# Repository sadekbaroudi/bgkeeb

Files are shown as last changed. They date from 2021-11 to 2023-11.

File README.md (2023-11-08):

# Pronunciation

Baby Groot Keyboard (bgkeeb)

This is a reversible 100mm x 100mm pcb with support for mx or choc switches (no hotswap), per key led, rotary encoders, and exposes the SDA/SCL/GND/VCC lines in the form of the pimoroni trackball pins (meaning you can add that as well, though the case doesn't support it, so you'll need to devise your own mechanism).

Given the pcb is so small, pcb prototype manufacturers will fab this for very cheap, or even free. As of this writing, nextpcb will ship fab and ship this keyboard 100% for free (in green only). jlcpcb will fab and ship these for $2 (USD).

# PCBs

There are two pcbs, the choc version and the mx version.

For the mx version, see the pcb/mx directory in the repository
For the choc version, see the pcb/mx directory in the repository

# Support me!

I have spent a lot of time and money designing prototypes, testing, developing, etc. Any contributions would be greatly appreciated!

If you don't want to, or can't afford to support me, please send me a message to let me know you've built one, along with pictures. Also, feel free to submit a pull request with pictures into this repository. I'd be happy to showcase your build.

Reddit: /u/sadekbaroudi
Discord: sadekbaroudi#1258



# Firmware

You can use the firmware found here:
https://github.com/sadekbaroudi/qmk_firmware/tree/master/keyboards/fingerpunch/bgkeeb/

zmk firmware here: https://github.com/ezxzeng/zmk-bgkeeb

# Pictures

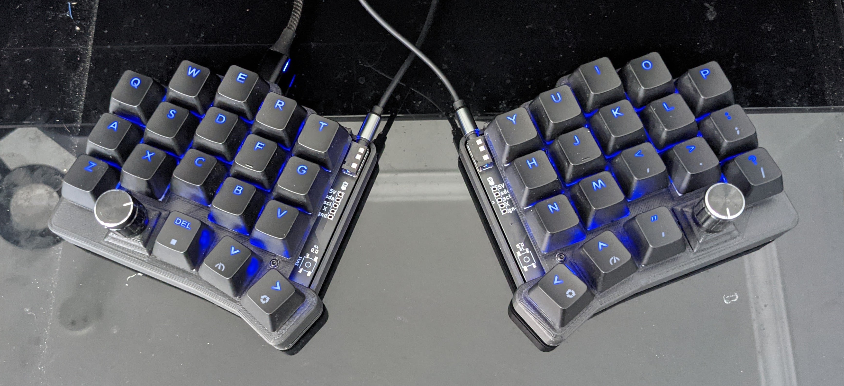
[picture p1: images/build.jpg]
build


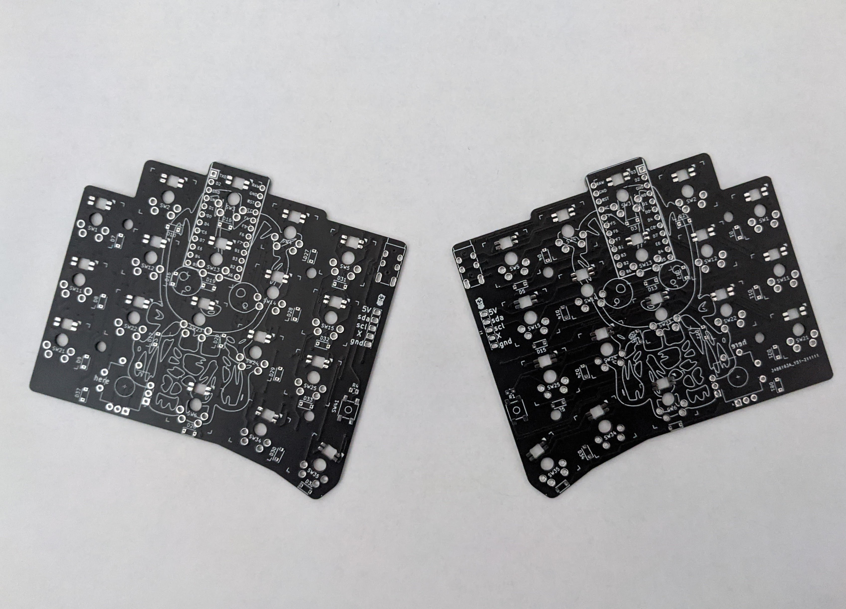
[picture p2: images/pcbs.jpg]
pcbs


# Submitted build pics

@ardakilic

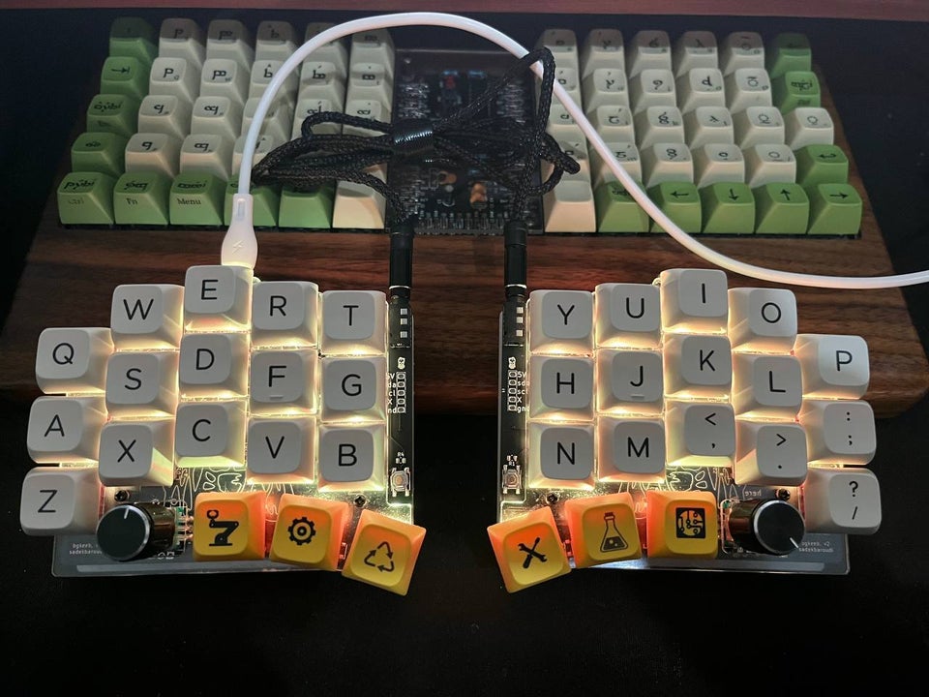
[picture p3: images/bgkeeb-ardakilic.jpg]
ardakilic-build


@carboncopy101

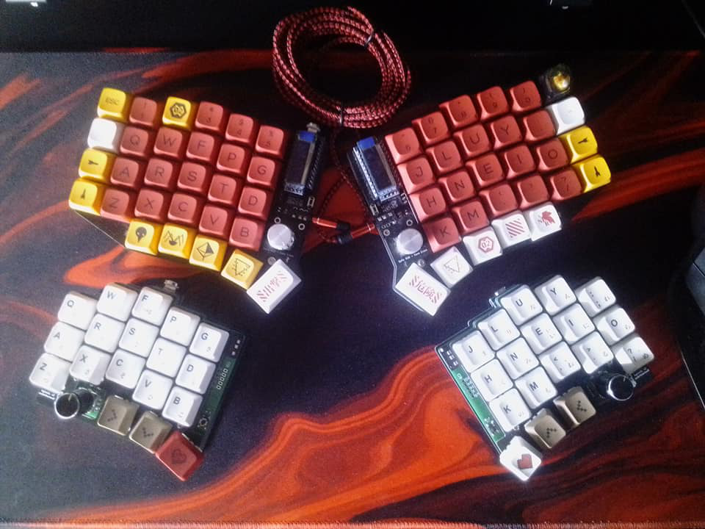
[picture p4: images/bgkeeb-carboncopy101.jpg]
cc101-build


@robopuff

cc101-build

@JulioPDX

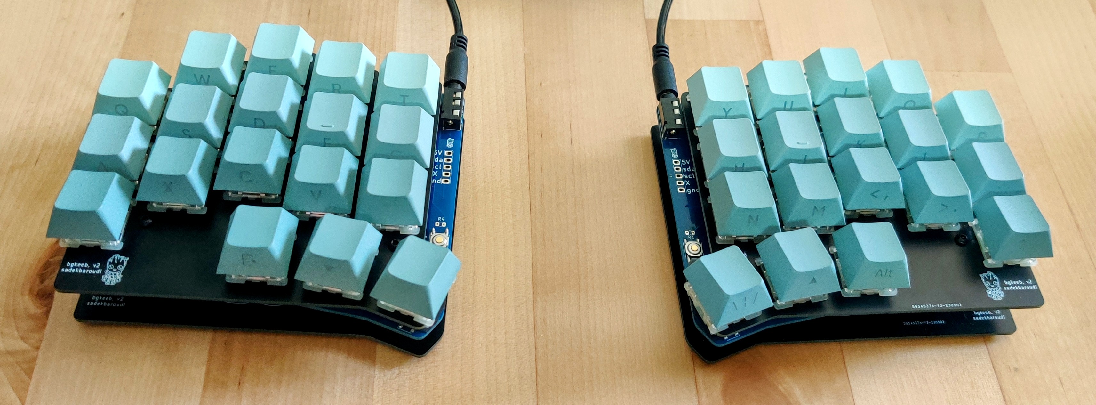
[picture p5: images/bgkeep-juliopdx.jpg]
juliopdx-build


@ezxzeng

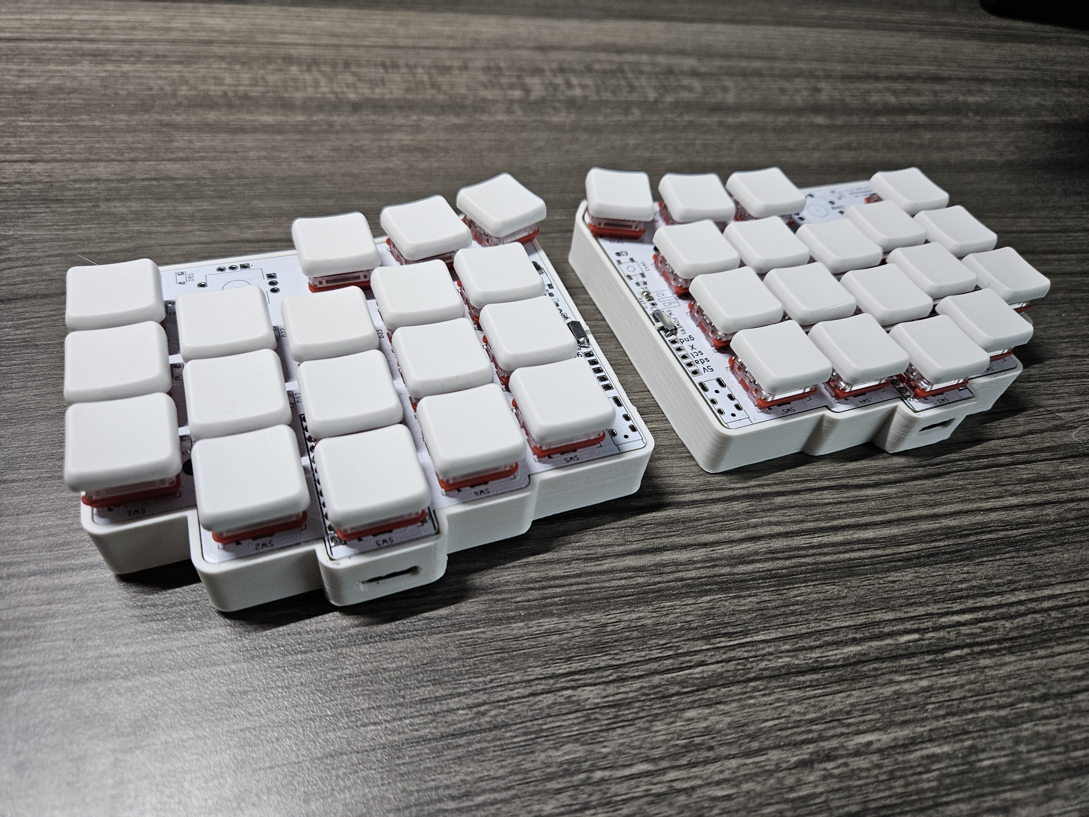
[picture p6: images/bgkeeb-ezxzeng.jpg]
ezxzeng-build

case for the wireless choc build found [here](https://cad.onshape.com/documents/f9433f7cbaacd819773968dc/w/7cd753696df5795c5e7db3c3/e/7a6c60eb671b22fb31dd6c76)

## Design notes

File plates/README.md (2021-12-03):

# FR-4 plates

Go into each directory, and fab the gerber.zip. 

You need the bottom plate and one of the two switchplates. If you are not going to use an encoder, use the no-encoder one

# Pictures

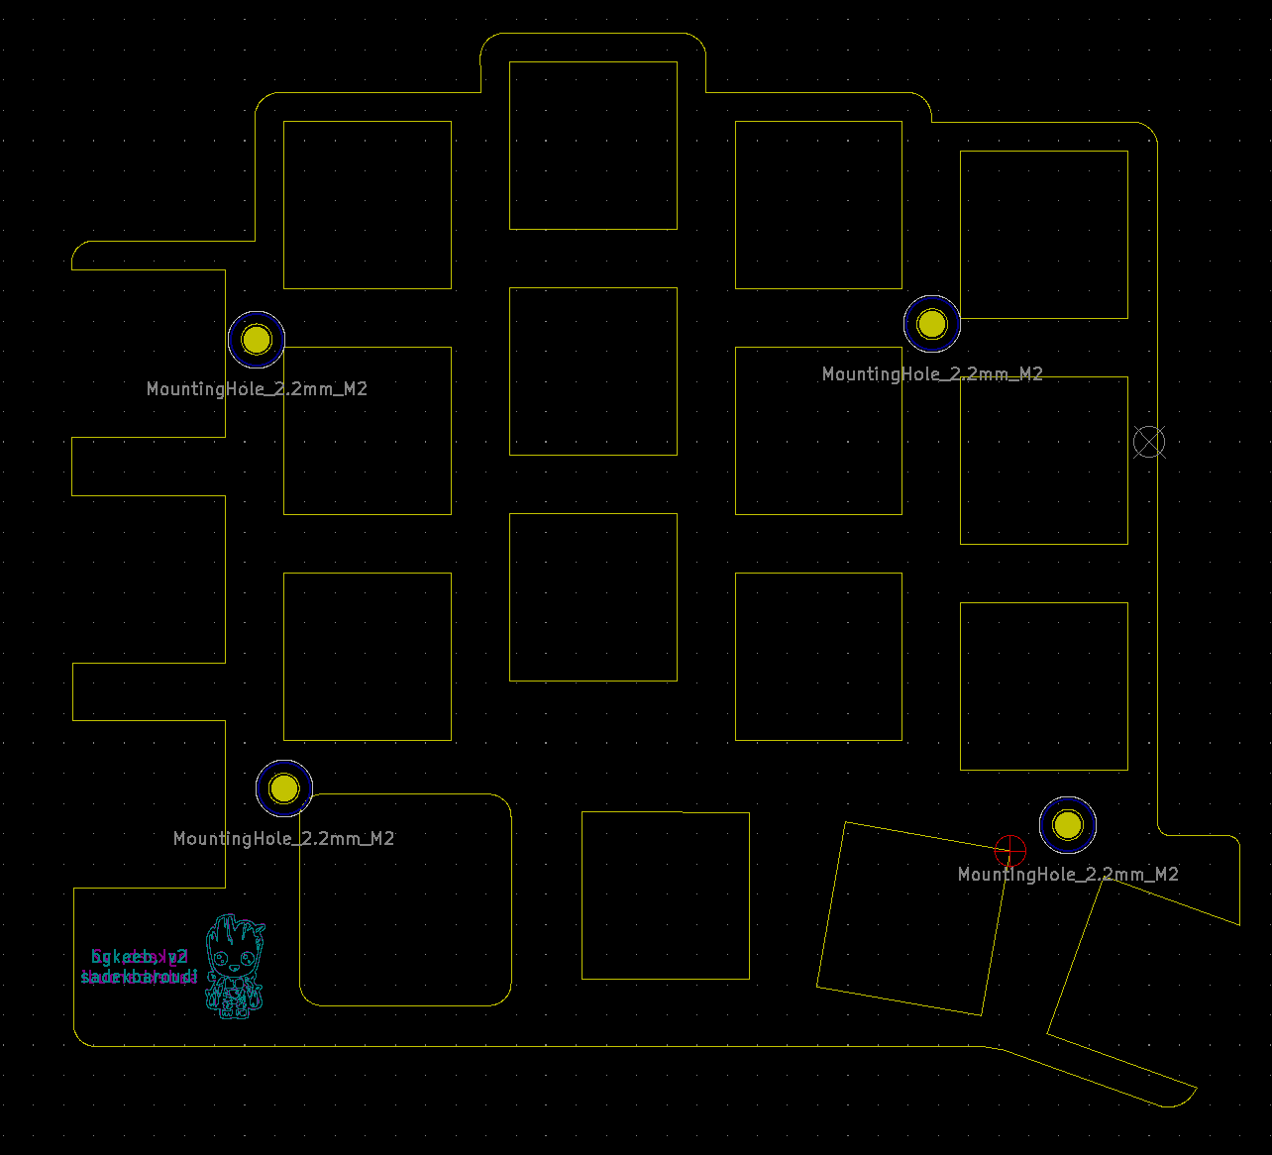
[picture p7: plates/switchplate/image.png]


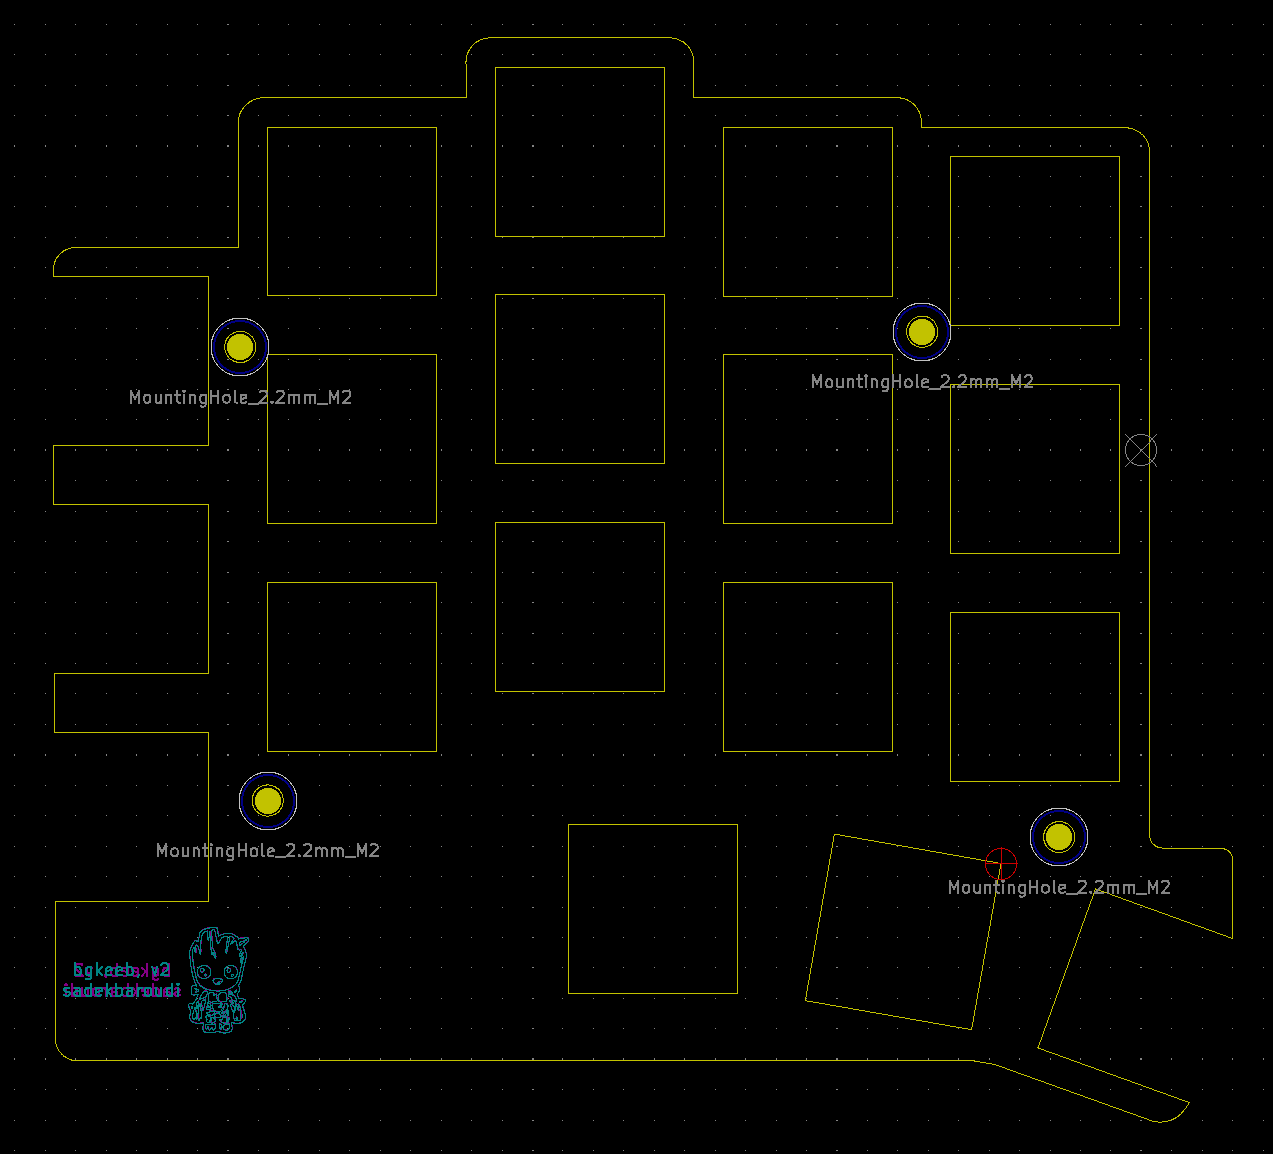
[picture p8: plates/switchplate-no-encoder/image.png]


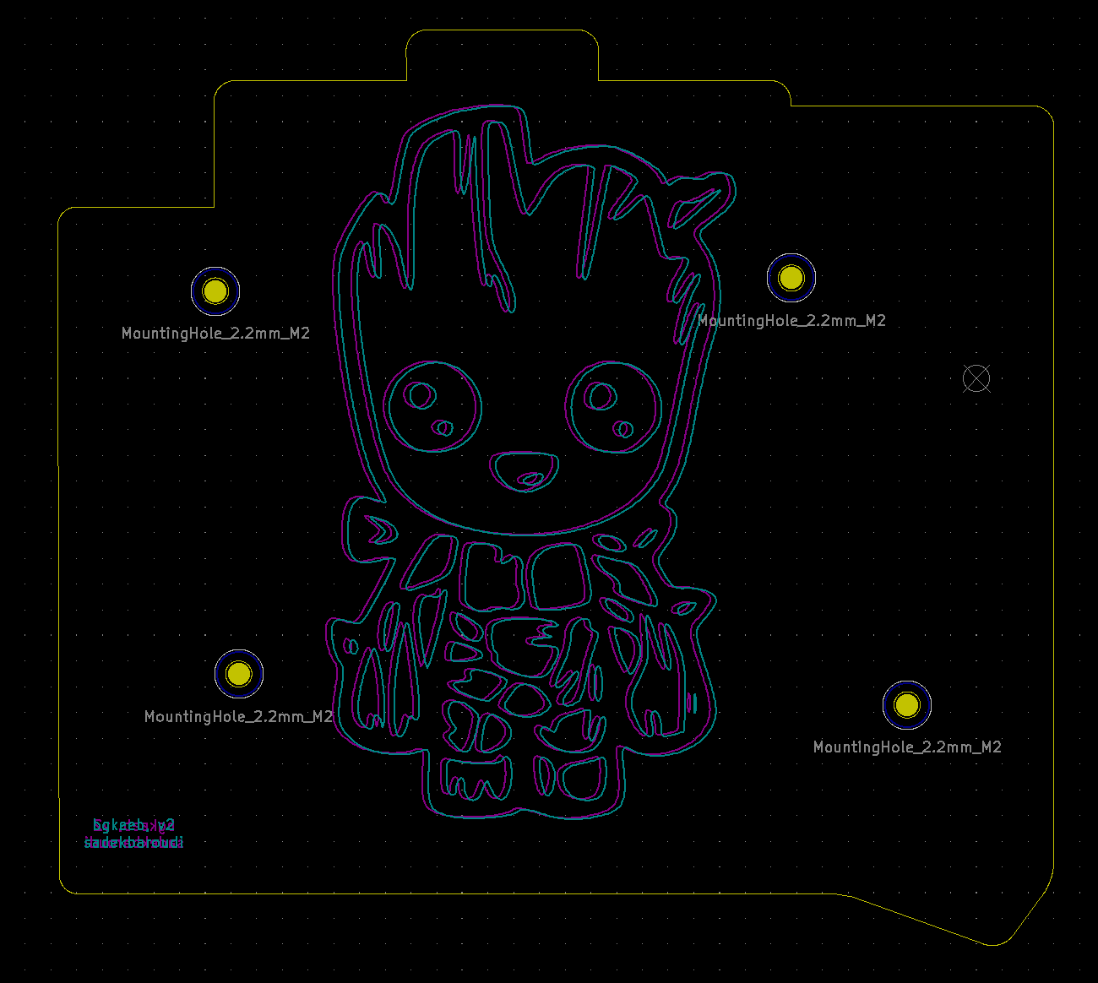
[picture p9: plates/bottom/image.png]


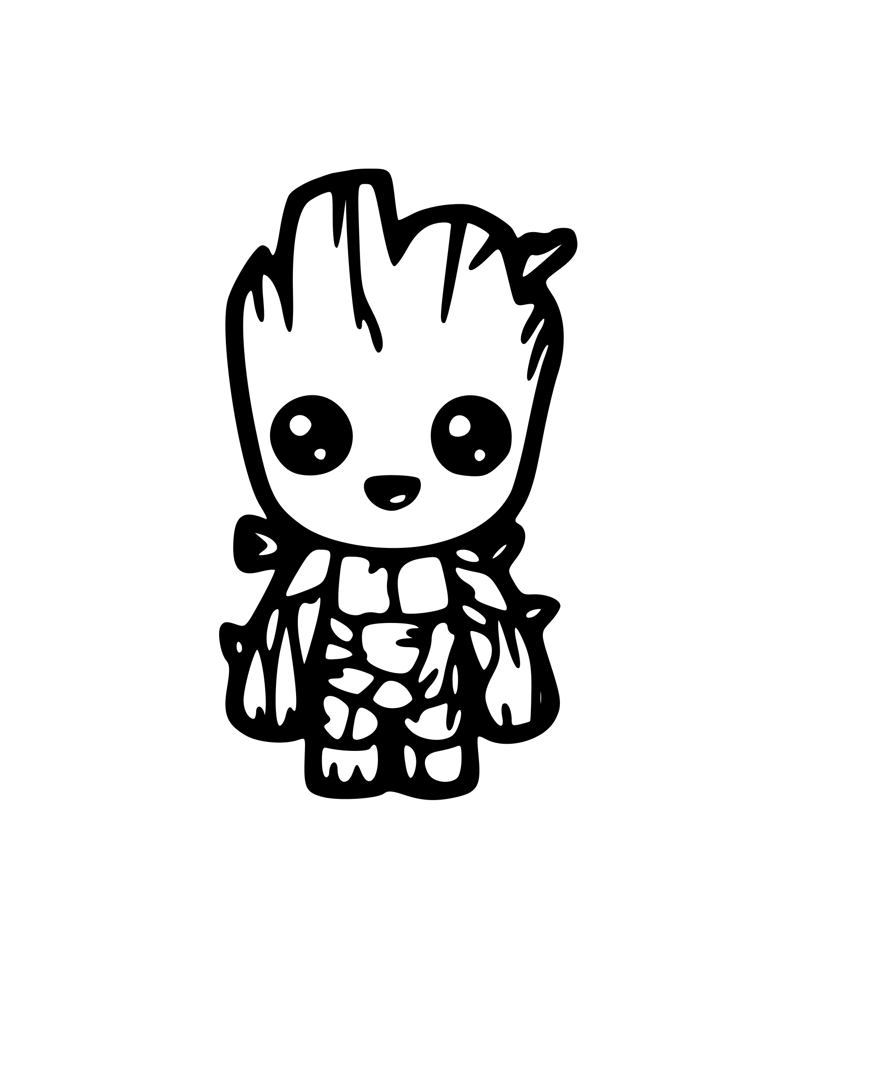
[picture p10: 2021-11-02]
svgs/Groot_Baby.png

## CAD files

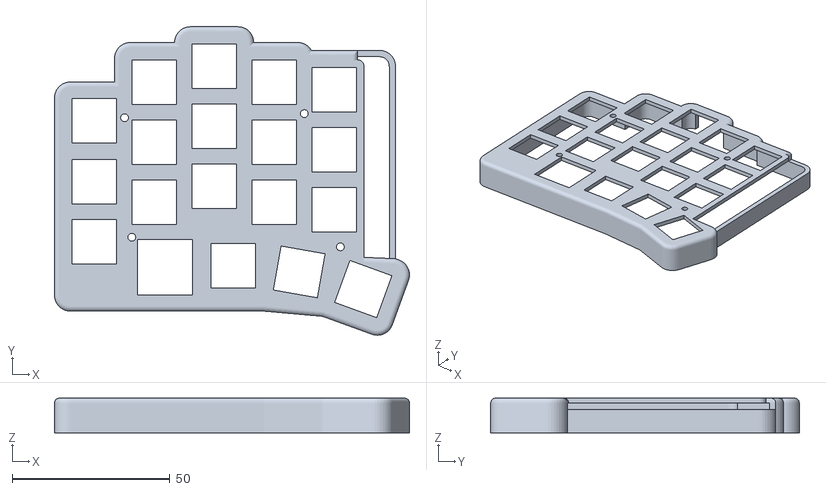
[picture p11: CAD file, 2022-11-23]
cases/case/left-switchbody-choc.stl
112.4 x 97.7 x 11.0

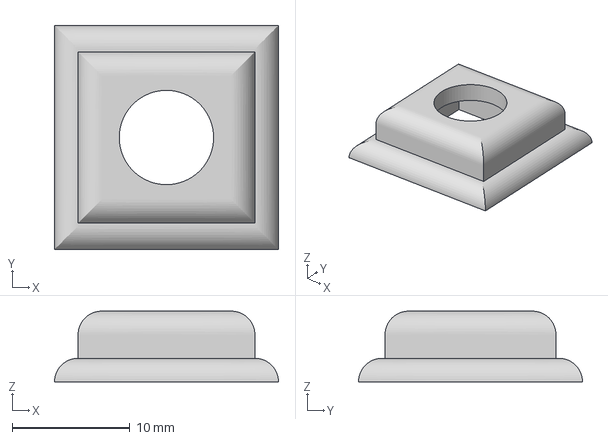
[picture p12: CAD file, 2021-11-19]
cases/covers/EC11-encoder-cap-small.3mf
19.0 x 19.0 x 6.00 mm

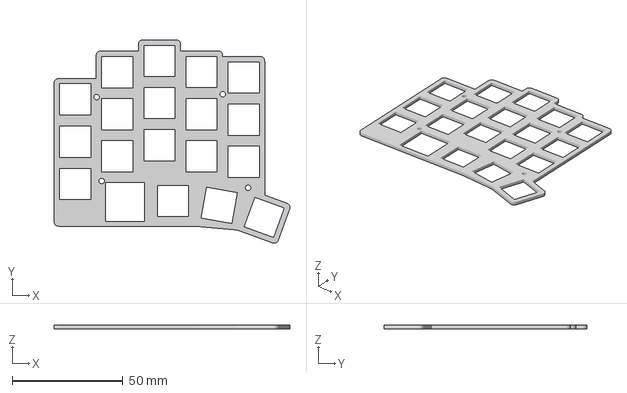
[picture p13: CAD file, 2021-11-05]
cases/plates/left-switchplate.3mf
106.4 x 91.7 x 1.60 mm

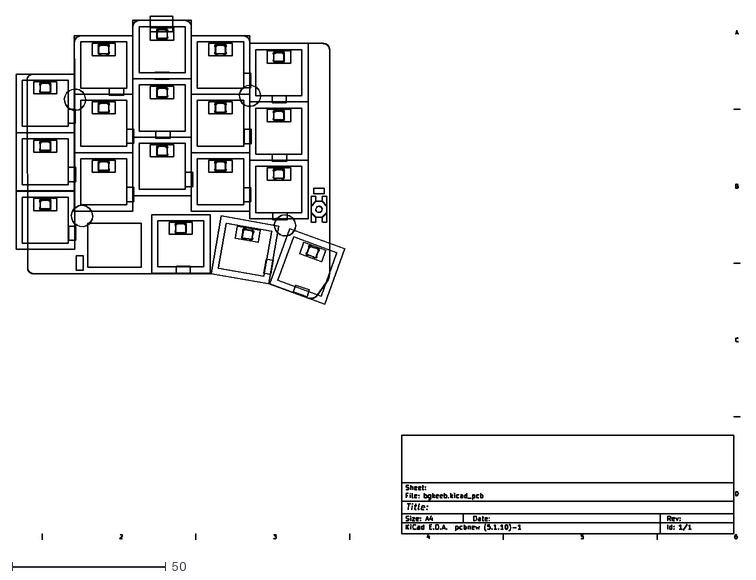
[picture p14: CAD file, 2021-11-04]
svgs/case-template.dxf
235.5 x 170.4

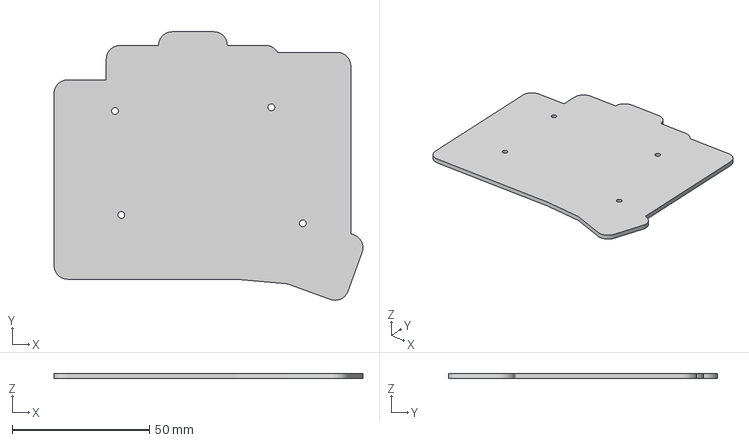
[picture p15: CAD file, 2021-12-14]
cases/case/left-bottomplate.3mf
112.4 x 97.7 x 2.00 mm

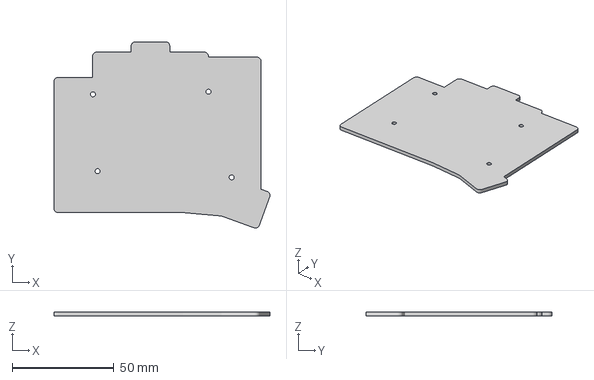
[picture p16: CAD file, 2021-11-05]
cases/plates/left-bottomplate.3mf
106.4 x 91.7 x 2.00 mm

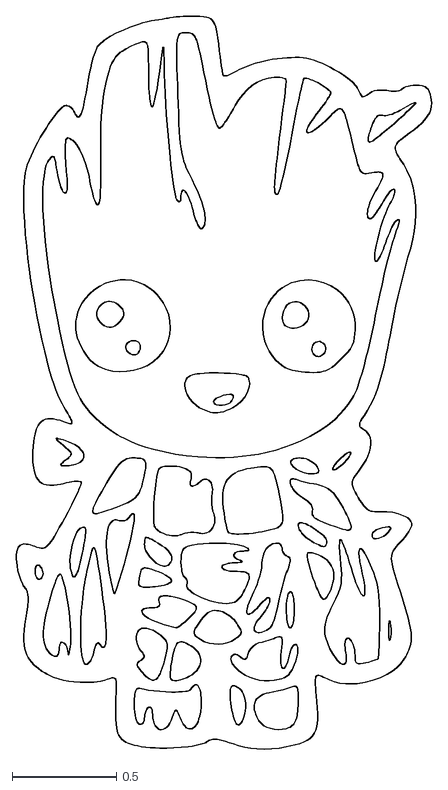
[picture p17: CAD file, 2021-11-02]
svgs/Groot_Baby.dxf
2.00 x 3.53

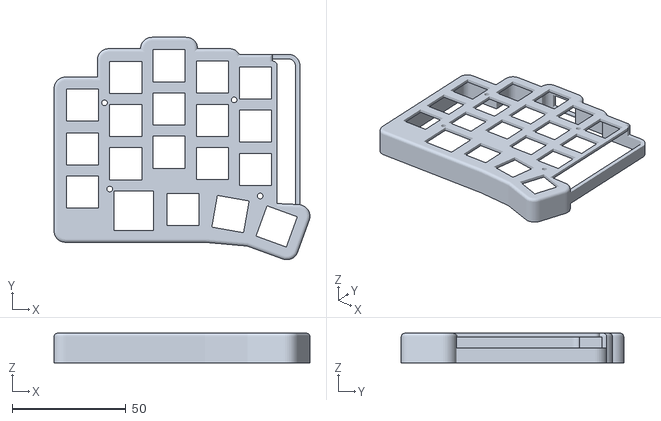
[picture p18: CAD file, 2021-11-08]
cases/case/left-switchbody-mx.stl
112.4 x 97.7 x 13.0

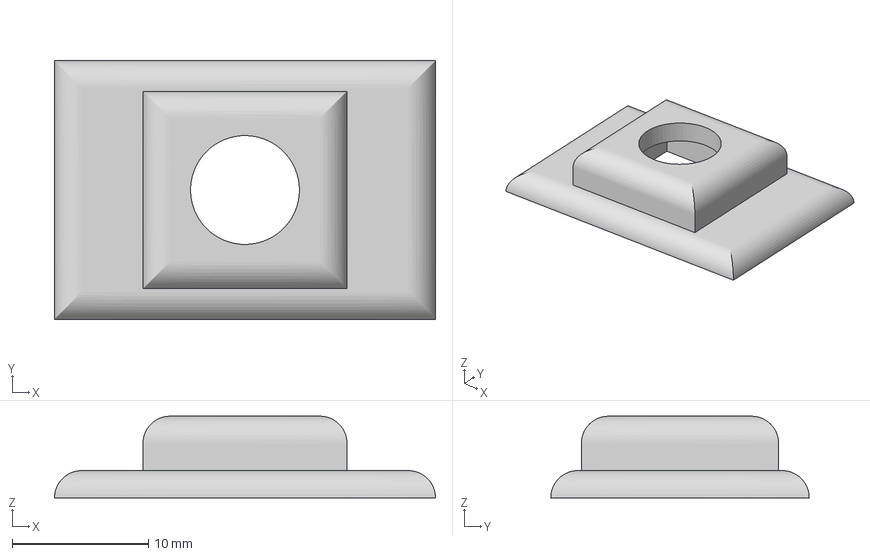
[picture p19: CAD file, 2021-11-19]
cases/covers/EC11-encoder-cap.3mf
28.0 x 19.0 x 6.00 mm

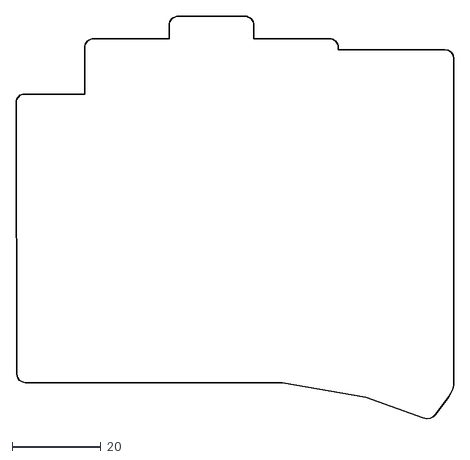
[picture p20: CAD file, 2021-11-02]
svgs/babykeeb-outline.dxf
98.4 x 90.7

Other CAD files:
cases/case/left-switchbody.3mf
cases/covers/EC11-encoder-cap-M2-screw-holes.3mf
cases/case/left-bottomplate.stl
cases/plates/left-bottomplate.stl
cases/plates/left-switchplate.stl

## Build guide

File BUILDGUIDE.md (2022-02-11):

# Parts

Note that all the links below are from major reputable elecronics sites. You can do this for much cheaper if you search for these same parts on aliexpress.com

For this pcb, here are the components you will need:

| Component | Quantity | Link |
| --- | --- | --- |
| MCU (Pro Micro compatible, Elite-c compatible, or nice!nano compatible | 2 | Google it, they're everywhere |
| SMD Diodes 0805 | 42 | https://www.lcsc.com/product-detail/Switching-Diode_TWGMC-1N4148W_C727110.html |
| SMD 10k resistor (optional) | 2 | https://www.lcsc.com/product-detail/Chip-Resistor-Surface-Mount_UNI-ROYAL-Uniroyal-Elec-0805W8F1002T5E_C17414.html |
| M2 10mm standoffs | 8 | https://keeb.io/products/m2-screws-and-standoffs?variant=47432051590 |
| M2 4-5mm screws | 16 | https://www.amazon.com/uxcell-0-4mm-Stainless-Socket-DIN912/dp/B01M5DVE9R |
| Reset switch | 2 | https://www.digikey.com/en/products/detail/c&k/PTS526%2520SM15%2520SMTR2%2520LFS/10056633 |
| TRRS jack | 2 | https://keeb.io/collections/diy-parts/products/trrs-jack-3-5mm |
| SK6812 mini-e LED (optional) | 36 | https://www.adafruit.com/product/4960 |
| EC11 Rotary encoder (optional) | 2 | https://www.adafruit.com/product/377 |
| Pimoroni trackball (optional) | 1 | https://shop.pimoroni.com/products/trackball-breakout |

# Case

You will need to have the case before you solder, since the switches are soldered to the pcb.

https://github.com/sadekbaroudi/bgkeeb/tree/master/cases/case

Print the left case and bottom plate. You can use your slicing software to do horizontal mirroring to print the right case and plate.

# Building

Building these is very straight forward. Solder all the components per the footprints on the board, in the following order:

Top side:
* Resistor
* Reset switch
* Aux jack

Bottom side:
* Diodes
* Per key leds
* Headers or socket for the Pro micro compatible MCU (recommend you do this before the switches, so you can solder the headers from the top of the pcb)
* Switches
* Pro micro (the pro micro should go in the correct direction, please be careful about this, as it's easy to put it in backwards)

Top side:
* Note that before starting on the rotary encoders, if your encoders have the wide legs on the sides, you should clip them, since this pcb does not have holes for those legs. Please note that I'm *not* talking about the sides that have 2 or 3 pins. Thoes are important to keep.
* Rotary encoders (Note: there is text 'here' on both sides of the pcb. While placing the encoder in from the top, make sure you put the encoder in the holes that are closest to the word 'here')

Note: Once you solder the pro micro, you can no longer access the solder points below it. So make sure everything is done before you do this

Also, If you add rotary encoders, there are some nice covers you can 3d print and put on top for a cleaner look. This is optional, but recommended as it looks much better. See the stls directly in this folder:
* https://github.com/sadekbaroudi/bgkeeb/tree/master/cases/covers

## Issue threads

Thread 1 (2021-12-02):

Request for fr4 top plate and backplate

carboncopy101, 2021-12-02:
Hi! Can I ask for a top plate and backplate gerber? This would be very nice to implement since pcb manufacturers make small pcbs for 2USD. Thanks!

sadekbaroudi, 2021-12-02:
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

I would have loved to make switch plates, but as you can see, in order to make it fit within the 100x100 limit, I can't fit this switch within the pcb outline. This is fine for the pcb, but if you make a switch plate, I can't fit a whole switch in there. However, I will try to do something that still works. Stay tuned.

sadekbaroudi, 2021-12-02:
Basically, this is what it's going to look like:

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

sadekbaroudi, 2021-12-03:
https://github.com/sadekbaroudi/bgkeeb/commit/290e493a76f80711c72a02e8e4b6a4424358d400

sadekbaroudi, 2021-12-03:
go to https://github.com/sadekbaroudi/bgkeeb/tree/master/plates

carboncopy101, 2022-01-31:
cool thanks man! Also I had the v1 fabricated. can you link me the steps on how to program the v1 left and right? Thanks again.

sadekbaroudi, 2022-01-31:
> cool thanks man! Also I had the v1 fabricated. can you link me the steps on how to program the v1 left and right? Thanks again.

As it turned out, I was mistaken and the v1 didn't require any special firmware. Build with the current instructions, and it should work fine on the v1 as well. Let me know if you run into any trouble.

carboncopy101, 2022-01-31:
Hello! Nice will update you as soon as I get some free time to work on it.

carboncopy101, 2022-02-01:
Hey! followed your instructions. I got this error:

QMK Firmware 0.14.32
ERROR fingerpunch/bgkeeb: Claims to support a community layout that does not exist: split_3x5_4
Making fingerpunch/bgkeeb with keymap default

anyway it still flashes fine. I tried all the keys except for the encoders. Ill send you pictures when I get and solder the switches. Thanks!

sadekbaroudi, 2022-02-01:
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

Interesting. I'll fix that, but glad it still works anyway. Enjoy!

Closed 2021-12-03.

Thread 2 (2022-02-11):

There are not enough holes to place EC11 rotary encoder.

azhizhinov, 2022-02-11:
Hello.
Thanks for your efforts.
Am I right, that 2 legs of EC11 should be removed, bolder ones, because there are no holes for them?
Thanks in advance.

azhizhinov, 2022-02-11:
I'll try. ;-)
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
Here the difference beetwin your PCB and the other one with rotary encoder.

sadekbaroudi, 2022-02-11:
Ah, that makes it much clearer! Yes, you can clip those legs. They have no electrical function.

azhizhinov, 2022-02-11:
Good.
Thank you.
Maybe a good idea to add that information to your buildguide. ;-)

sadekbaroudi, 2022-02-11:
Fair point! Done: https://github.com/sadekbaroudi/bgkeeb/commit/fb79d040074173b2201d44e4a0736fff486bdede

Closed 2022-02-11.

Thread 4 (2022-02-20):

Can you, please, explain how ProMicro should be soldered.

azhizhinov, 2022-02-20:
Hello.
I beg your pardon.
Can you, please, explain how ProMicro should be soldered.
Accordingly to bildguide.md, ProMicros should be placed under PCBs (left or right), but how they should be oriented, with CPUs up to PCBs?
Maybe some photos?
Sorry.
Thanks for your time.

sadekbaroudi, 2022-02-20:
Almost all (if not all) pcbs have the footprint for the pro micro with silkscreen to show which pins go where, as shown here:
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

As long as you make sure that the pro micro has the two GND pins placed on the two GND pins circled in the picture, then it will work. So, on one half of the pcb, the pro micro will be soldered in one orientation, and on the other half it will be the opposite

Closed 2022-02-20.

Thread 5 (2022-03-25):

Can't make them work

robopuff, 2022-03-25:
So I've built one but can't make it work. Both are flashed with left and right settings and when I plug them in separately, they seem to work (both as a left one tho), but whenever I add the TRS cable, it just goes dark - the LEDs turn off and computer doesn't recognize it at all :(

sadekbaroudi, 2022-03-26:
can you share a picture of your build? and how you soldered everything? especially the trrs jacks

robopuff, 2022-03-26:
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

sadekbaroudi, 2022-03-26:
looks good to me... some more questions...

* What command did you use to build the firmware, and which repository did you use? I can try to flash the same firmware and see what happens on mine
* Are you using a trrs cable, or trs? if trs, it won't work, you need trrs. Also, make sure it's plugged in ALL the way. I had that problem with my adux, and took me two days to figure it out :O

robopuff, 2022-03-28:
Commands used:
```
$ make fingerpunch/bgkeeb:default:avrdude-split-left
$ make fingerpunch/bgkeeb:default:avrdude-split-right
```

but the issue was cable, I've grabbed one from the stack and it had two last pins connected together (dunno why it was made like that, weird premade cable), now that I've used different one, it all works correctly - can share some more photos from finished buld :)

sadekbaroudi, 2022-03-28:
yay! so glad to hear

Closed 2022-03-28.

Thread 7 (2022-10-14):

Diode orientation

gelbermann, 2022-10-14:
Hi!
First of all, this keeb looks absolutely great. I printed some PCBs right when it was posted on reddit, and am finally getting around to building it. Thank you for making it possible!

I have a newbie question:
How can I tell the diode orientation? Unless I'm missing something, I don't see any markings on the PCBs.

Thanks!

sadekbaroudi, 2022-10-21:
hi @gelbermann - so sorry for the delay! I didn't see this issue posted. So, there should be a line on one side of the rectangle silk screen marking. The side with the line should line up with the line on the diode!

Also, feel free to join the fingerpunch discord server, and reach out in the #help channel. Very responsive and friendly group in there.
https://fingerpunch.xyz/discord

Closed 2022-10-21.

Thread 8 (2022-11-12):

Which direction should LEDs honour, the top, or the bottom?

Ardakilic, 2022-11-12:
Hello,

Which direction's arrows should LEDs honour for orientation?

Which direction should the LED's indicator be same with the tick on the pcb, the back (where we solder), or the front one (where switches will sit)?

Thanks in advance!

Ardakilic, 2022-11-12:
OK, glad it's open source, the led orientation should honor the side that you apply the solder, like the other side has no silk screen. Thanks for making this PCB available for us!

sadekbaroudi, 2022-11-13:
>

Hi @Ardakilic - My pleasure! Glad you figured it out. Let me know if you have any other questions!

sadekbaroudi, 2022-11-13:
To be clear, the led light should face the opposite direction that you are soldering. This way, the led lighting faces up.

Ardakilic, 2022-11-13:
@sadekbaroudi Heya, first of all thanks! I figured it out, but I was not sure the orientation of the LED, while the orientation is looking up, should honor the top side mark or bottom. That confused me (while you're looking from top side, the mark on the LED and silkscreen do not match)

I also have some issues with encoders with default layout (assuming master is left on default). I soldered the left one horizontally, and the right one vertically. Although the buttons work, the encoders don't. Also the right one works reversed only when right one is connected. I will dig for it further and open an issue if I cannot sort it out.

Thanks again!

Closed 2022-11-12.

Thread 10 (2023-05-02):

Why is the 10k resistor optional

JulioPDX, 2023-05-02:
Hello,

I'm new to building keyboards and was wondering why the 10k resistor is optional? Thank you for making this available to the community!

ShamalLakshan, 2025-07-31:
I think the resistor is for the LED circuit and only needed if you decide to add LEDs to the keyboard build.

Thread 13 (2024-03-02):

wireless mx pls :'(

Merlinov, 2024-03-02:
wireless mx pls :'(

sadekbaroudi, 2024-03-03:
@Merlinov - you can run this wireless as is! nice!nano has inline battery connections, and this keyboard is compatible with the nice!nano footprint. The only real thing missing would be an on/off switch.

Merlinov, 2024-03-03:
I decided that sweep36 with glp ks-33 is the best idea for me. i need some easy to go wireless 36k keeb on which I will not feel discomfort compared to my main one. :'(
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

Merlinov, 2024-03-03:
why sweep36 ks-27 didnt have on/off switch to?(

sadekbaroudi, 2024-03-03:
> why sweep36 ks-27 didnt have a on/off switch too?( and what about the cases? are they compatible with ks-27?

sweep36 does have an on/off switch, but it's the swweeep pcb:
https://github.com/sadekbaroudi/sweep36/tree/master/swweeep

That PCB doesn't have KS-27 support though.

> and what about the cases? are they compatible with ks-27?
Yes, choc cases and glp cases are generally compatible with each other. You will need to find MX keycaps with choc spacing though, since this pcb has choc spacing.

Please carefully read through the readme. I have explained all of what you're asking there.

atharva-vadeyar, 2024-09-25:
Hi - how do you use the nice!nano to power and control the SK6182 MINI-E LEDs? I thought the LEDs needed at least 3.7V for power and control and the nice!nano can only output 3.3V. I couldn't see a level shifter of any kind on the schematic so not sure how/if this works

Thanks :D

sadekbaroudi, 2024-09-25:
@atharva-vadeyar - You are correct, there is no level shifter. It does technically need at least 3.7v, but I have tested on many boards, and the 3.3v works fine with the mini-e leds :)

atharva-vadeyar, 2024-09-25:
> @atharva-vadeyar - You are correct, there is no level shifter. It does technically need at least 3.7v, but I have tested on many boards, and the 3.3v works fine with the mini-e leds :)
Thank you!

And does the control input for the LED need to come from the Uart Tx or can it come from any GPIO?

atharva-vadeyar, 2024-09-25:
And again, sorry to bug you haha but how does the charging of the LiPo battery work? There isn’t a specific charging socket or a USB port or anything. Where does it get power from?

sadekbaroudi, 2024-09-25:
> And does the control input for the LED need to come from the Uart Tx or can it come from any GPIO?

It can technically come from any, but the pcb is using the uart tx, as you noticed. It's multi-purpose gpio, so it should be fine.

> And again, sorry to bug you haha but how does the charging of the LiPo battery work? There isn’t a specific charging socket or a USB port or anything. Where does it get power from?

The nice!nano has built in charging IC. So you can directly wire the battery to the controller's B+ and B- pins (they are the top ones on both sides, see nice!nano docs). Then when you plug in the nice!nano via usb, it charges the battery

atharva-vadeyar, 2024-09-26:
Hi! Thanks for your help!

I was looking at the pin diagram and I noticed the diagram in the datasheet and the diagram on the footprint you used (and other footprints I've found) for the SK6812MINI-E has the D_IN and D_OUT mixed up. Have you noticed anything similar? Has it affected the LED function in any way? Or have I just found an incorrect datasheet

Closed 2024-03-03.

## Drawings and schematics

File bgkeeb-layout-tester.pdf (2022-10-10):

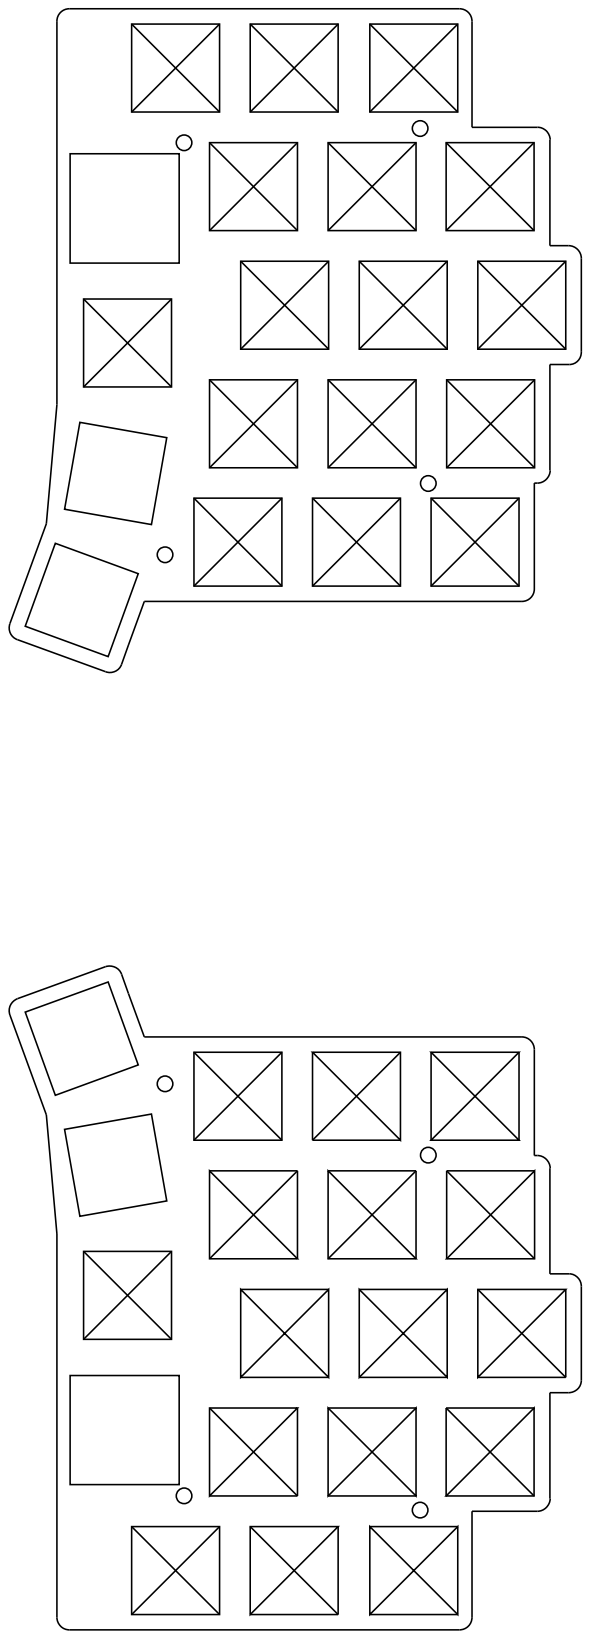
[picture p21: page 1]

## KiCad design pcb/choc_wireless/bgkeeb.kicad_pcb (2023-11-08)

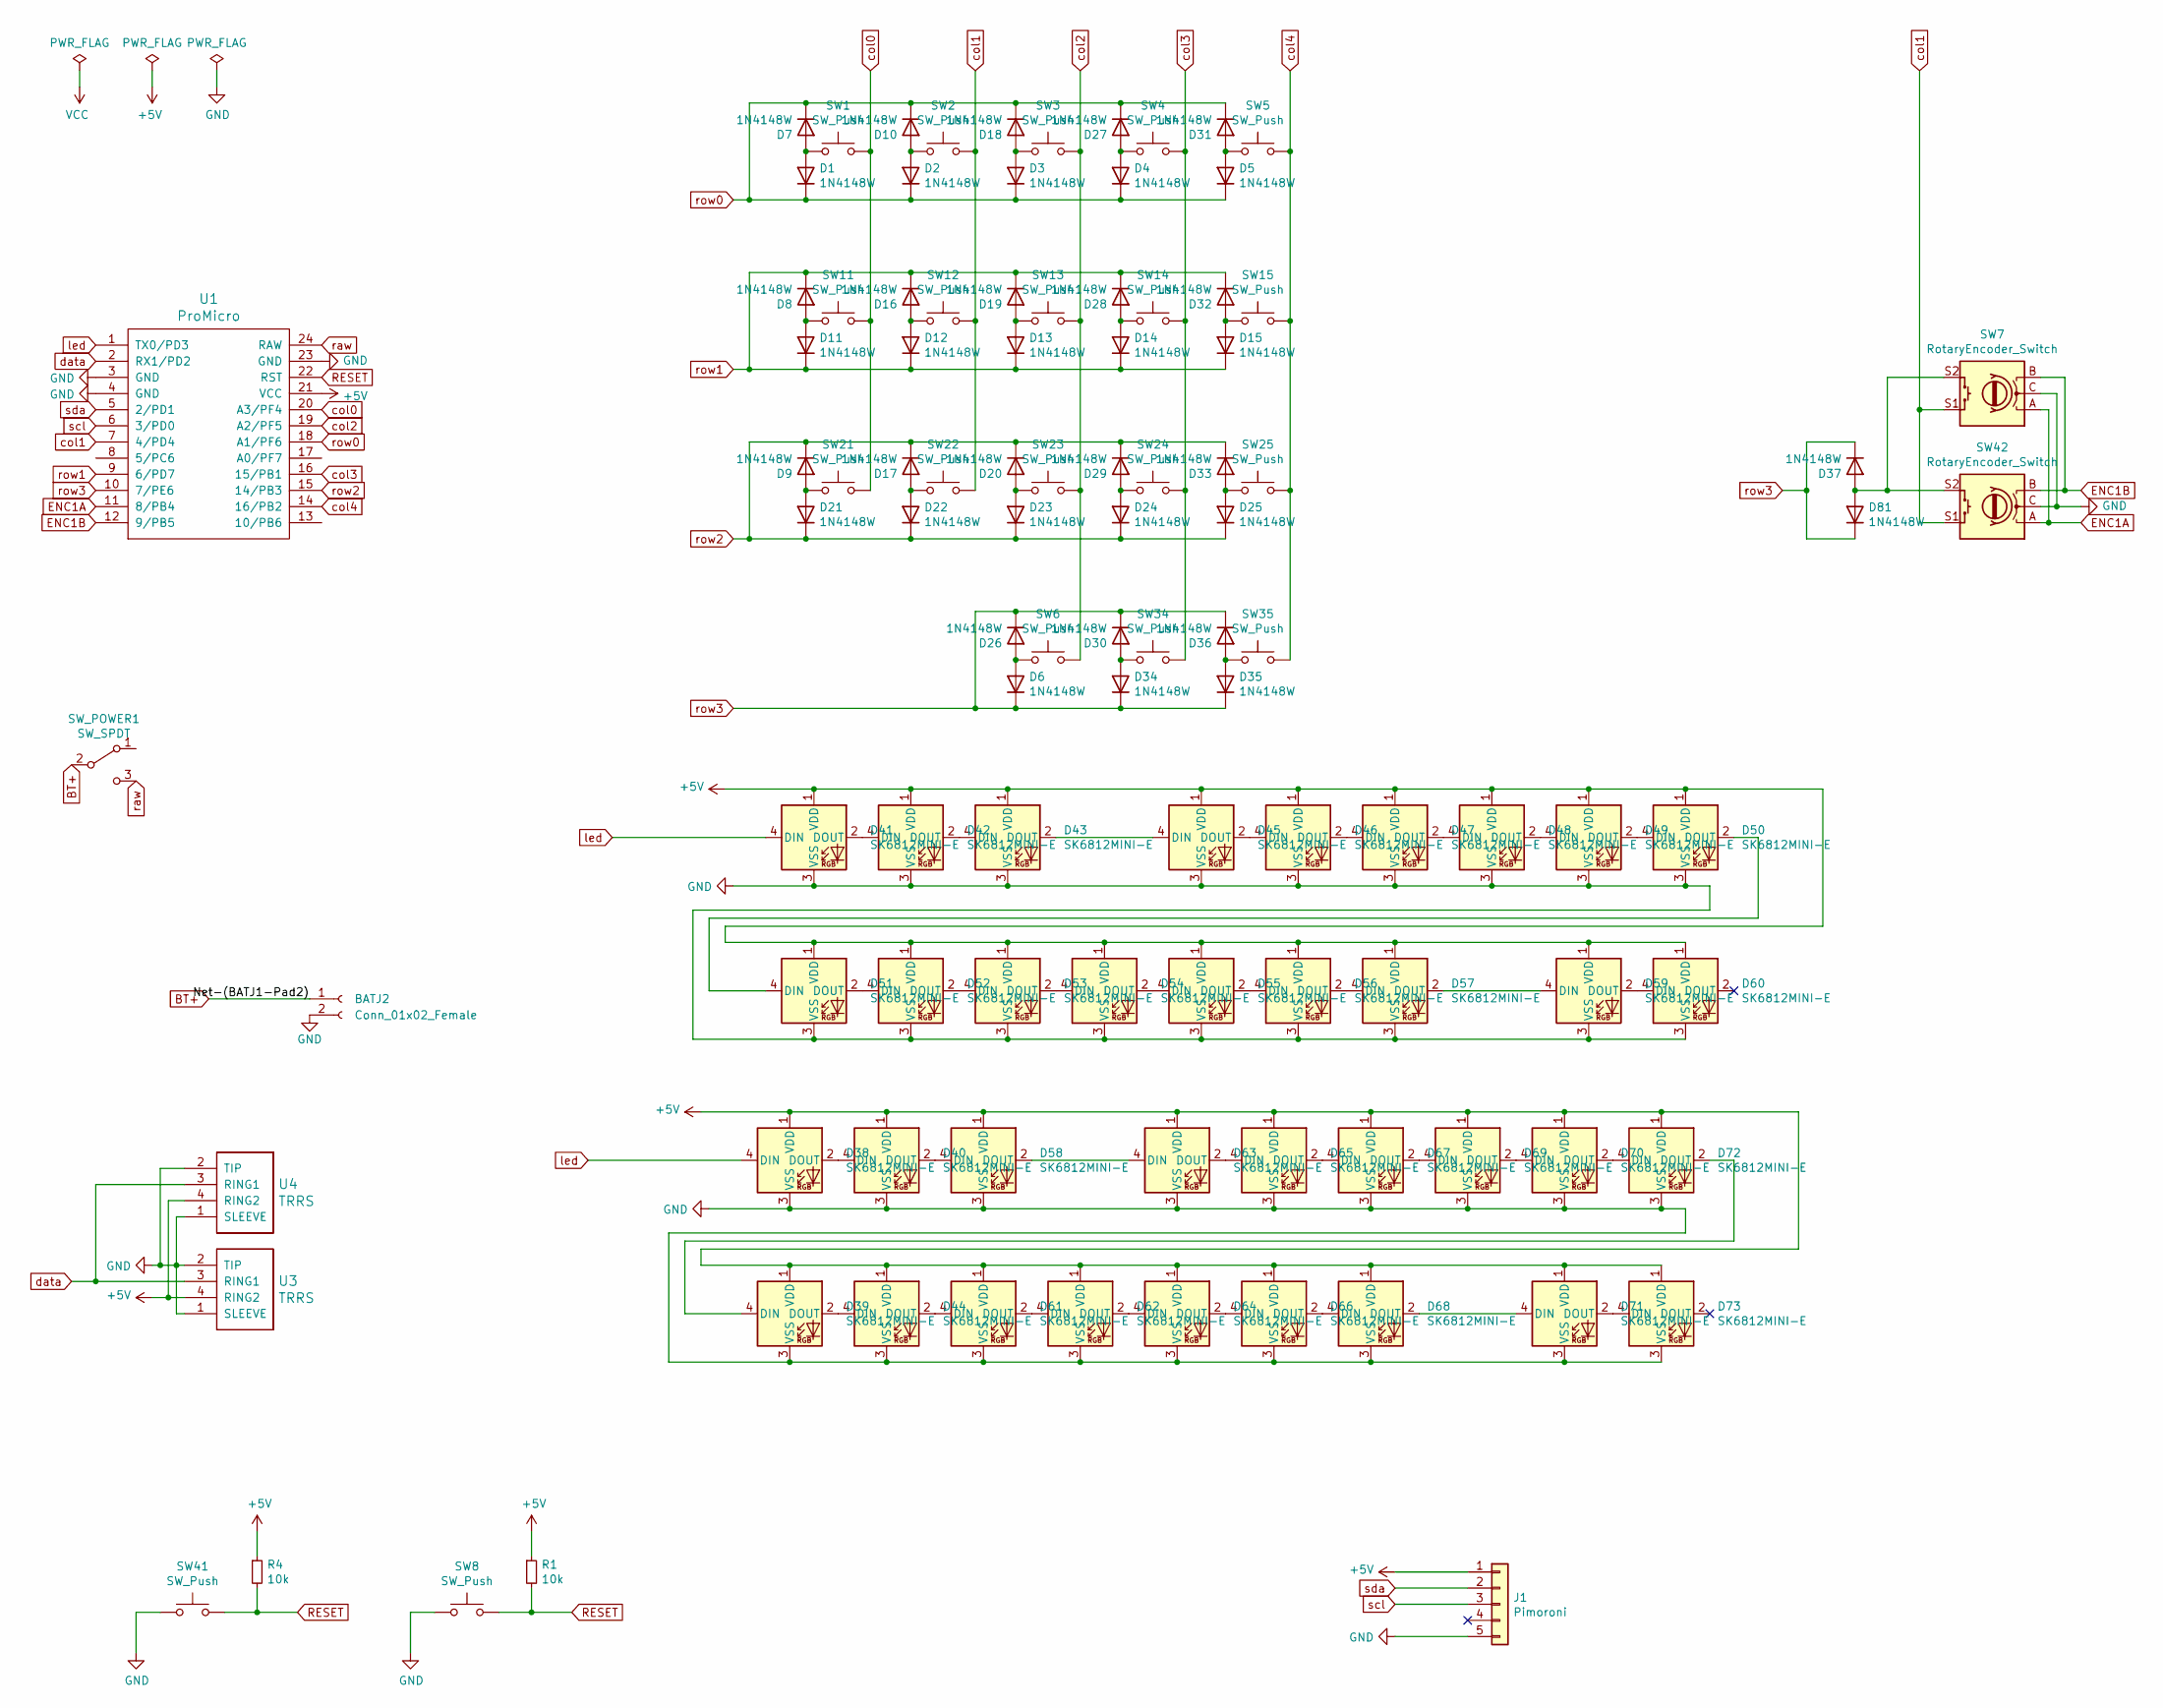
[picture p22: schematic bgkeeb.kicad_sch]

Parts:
BATJ2: Conn_01x02_Female; JST_PH_S2B-PH-K_1x02_P2.00mm_Horizontal_reversible
D1, D2, D3, D4, D5, D6, D7, D8, D9, D10, D11, D12, D13, D14, D15, D16, D17, D18, D19, D20, D21, D22, D23, D24, D25, D26, D27, D28, D29, D30, D31, D32, D33, D34, D35, D36, D37, D81: 1N4148W; D_SOD-123; LCSC C727110
D38, D39, D40, D41, D42, D43, D44, D45, D46, D47, D48, D49, D50, D51, D52, D53, D54, D55, D56, D57, D58, D59, D60, D61, D62, D63, D64, D65, D66, D67, D68, D69, D70, D71, D72, D73: SK6812MINI-E; MX_SK6812MINI-E
J1: Pimoroni; pimoroni
R1, R4: 10k; R_0805_2012Metric; LCSC C17414
SW1, SW2, SW3, SW4, SW5, SW6, SW11, SW12, SW13, SW14, SW15, SW21, SW22, SW23, SW24, SW25, SW34, SW35: SW_Push; SW_PG1350_reversible
SW7, SW42: RotaryEncoder_Switch; RotaryEncoder_EC11-no-legs
SW8, SW41: SW_Push; SKQG-1155865
SW_POWER1: SW_SPDT; SW_SPDT_PCM12_reversible
U1: ProMicro; ArduinoProMicro
U3, U4: TRRS; TRRS-PJ-320A

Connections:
+5V: D38.1 (VDD), D39.1 (VDD), D40.1 (VDD), D41.1 (VDD), D42.1 (VDD), D43.1 (VDD), D44.1 (VDD), D45.1 (VDD), D46.1 (VDD), D47.1 (VDD), D48.1 (VDD), D49.1 (VDD), D50.1 (VDD), D51.1 (VDD), D52.1 (VDD), D53.1 (VDD), D54.1 (VDD), D55.1 (VDD), D56.1 (VDD), D57.1 (VDD), D58.1 (VDD), D59.1 (VDD), D60.1 (VDD), D61.1 (VDD), D62.1 (VDD), D63.1 (VDD), D64.1 (VDD), D65.1 (VDD), D66.1 (VDD), D67.1 (VDD), D68.1 (VDD), D69.1 (VDD), D70.1 (VDD), D71.1 (VDD), D72.1 (VDD), D73.1 (VDD), J1.1, R1.1, R4.1, U1.21 (VCC), U3.4 (RING2), U4.4 (RING2)
BT+: SW_POWER1.2 (B); also elsewhere on the board
ENC1A: SW7.A, SW42.A, U1.11 (8/PB4)
ENC1B: SW7.B, SW42.B, U1.12 (9/PB5)
GND: D38.3 (VSS), D39.3 (VSS), D40.3 (VSS), D41.3 (VSS), D42.3 (VSS), D43.3 (VSS), D44.3 (VSS), D45.3 (VSS), D46.3 (VSS), D47.3 (VSS), D48.3 (VSS), D49.3 (VSS), D50.3 (VSS), D51.3 (VSS), D52.3 (VSS), D53.3 (VSS), D54.3 (VSS), D55.3 (VSS), D56.3 (VSS), D57.3 (VSS), D58.3 (VSS), D59.3 (VSS), D60.3 (VSS), D61.3 (VSS), D62.3 (VSS), D63.3 (VSS), D64.3 (VSS), D65.3 (VSS), D66.3 (VSS), D67.3 (VSS), D68.3 (VSS), D69.3 (VSS), D70.3 (VSS), D71.3 (VSS), D72.3 (VSS), D73.3 (VSS), J1.5, SW7.C, SW8.1, SW41.1, SW42.C, U1.3 (GND), U1.4 (GND), U1.23 (GND), U3.1 (SLEEVE), U3.2 (TIP), U4.1 (SLEEVE), U4.2 (TIP); also elsewhere on the board
unnamed: D1.2 (A), D7.2 (A), SW1.1
unnamed: D2.2 (A), D10.2 (A), SW2.1
unnamed: D8.2 (A), D11.2 (A), SW11.1
unnamed: D12.2 (A), D16.2 (A), SW12.1
unnamed: D13.2 (A), D19.2 (A), SW13.1
unnamed: D14.2 (A), D28.2 (A), SW14.1
unnamed: D15.2 (A), D32.2 (A), SW15.1
unnamed: D17.2 (A), D22.2 (A), SW22.1
unnamed: D3.2 (A), D18.2 (A), SW3.1
unnamed: D20.2 (A), D23.2 (A), SW23.1
unnamed: D9.2 (A), D21.2 (A), SW21.1
unnamed: D24.2 (A), D29.2 (A), SW24.1
unnamed: D25.2 (A), D33.2 (A), SW25.1
unnamed: D6.2 (A), D26.2 (A), SW6.1
unnamed: D4.2 (A), D27.2 (A), SW4.1
unnamed: D30.2 (A), D34.2 (A), SW34.1
unnamed: D5.2 (A), D31.2 (A), SW5.1
unnamed: D35.2 (A), D36.2 (A), SW35.1
unnamed: D37.2 (A), D81.2 (A), SW7.S2, SW42.S2
unnamed: D38.2 (DOUT), D40.4 (DIN)
unnamed: D39.4 (DIN), D72.2 (DOUT)
unnamed: D39.2 (DOUT), D44.4 (DIN)
unnamed: D40.2 (DOUT), D58.4 (DIN)
unnamed: D41.2 (DOUT), D42.4 (DIN)
unnamed: D42.2 (DOUT), D43.4 (DIN)
unnamed: D43.2 (DOUT), D45.4 (DIN)
unnamed: D44.2 (DOUT), D61.4 (DIN)
unnamed: D45.2 (DOUT), D46.4 (DIN)
unnamed: D46.2 (DOUT), D47.4 (DIN)
unnamed: D47.2 (DOUT), D48.4 (DIN)
unnamed: D48.2 (DOUT), D49.4 (DIN)
unnamed: D49.2 (DOUT), D50.4 (DIN)
unnamed: D50.2 (DOUT), D51.4 (DIN)
unnamed: D51.2 (DOUT), D52.4 (DIN)
unnamed: D52.2 (DOUT), D53.4 (DIN)
unnamed: D53.2 (DOUT), D54.4 (DIN)
unnamed: D54.2 (DOUT), D55.4 (DIN)
unnamed: D55.2 (DOUT), D56.4 (DIN)
unnamed: D56.2 (DOUT), D57.4 (DIN)
unnamed: D57.2 (DOUT), D59.4 (DIN)
unnamed: D58.2 (DOUT), D63.4 (DIN)
unnamed: D59.2 (DOUT), D60.4 (DIN)
unnamed: D61.2 (DOUT), D62.4 (DIN)
unnamed: D62.2 (DOUT), D64.4 (DIN)
unnamed: D63.2 (DOUT), D65.4 (DIN)
unnamed: D64.2 (DOUT), D66.4 (DIN)
unnamed: D65.2 (DOUT), D67.4 (DIN)
unnamed: D66.2 (DOUT), D68.4 (DIN)
unnamed: D67.2 (DOUT), D69.4 (DIN)
unnamed: D68.2 (DOUT), D71.4 (DIN)
unnamed: D69.2 (DOUT), D70.4 (DIN)
unnamed: D70.2 (DOUT), D72.4 (DIN)
unnamed: D71.2 (DOUT), D73.4 (DIN)
RESET: R1.2, R4.2, SW8.2, SW41.2, U1.22 (RST)
col0: SW1.2, SW11.2, SW21.2, U1.20 (A3/PF4)
col1: SW2.2, SW7.S1, SW12.2, SW22.2, SW42.S1, U1.7 (4/PD4)
col2: SW3.2, SW6.2, SW13.2, SW23.2, U1.19 (A2/PF5)
col3: SW4.2, SW14.2, SW24.2, SW34.2, U1.16 (15/PB1)
col4: SW5.2, SW15.2, SW25.2, SW35.2, U1.14 (16/PB2)
data: U1.2 (RX1/PD2), U3.3 (RING1), U4.3 (RING1)
led: D38.4 (DIN), D41.4 (DIN), U1.1 (TX0/PD3)
raw: SW_POWER1.3 (C), U1.24 (RAW)
row0: D1.1 (K), D2.1 (K), D3.1 (K), D4.1 (K), D5.1 (K), D7.1 (K), D10.1 (K), D18.1 (K), D27.1 (K), D31.1 (K), U1.18 (A1/PF6)
row1: D8.1 (K), D11.1 (K), D12.1 (K), D13.1 (K), D14.1 (K), D15.1 (K), D16.1 (K), D19.1 (K), D28.1 (K), D32.1 (K), U1.9 (6/PD7)
row2: D9.1 (K), D17.1 (K), D20.1 (K), D21.1 (K), D22.1 (K), D23.1 (K), D24.1 (K), D25.1 (K), D29.1 (K), D33.1 (K), U1.15 (14/PB3)
row3: D6.1 (K), D26.1 (K), D30.1 (K), D34.1 (K), D35.1 (K), D36.1 (K), D37.1 (K), D81.1 (K), U1.10 (7/PE6)
scl: J1.3, U1.6 (3/PD0)
sda: J1.2, U1.5 (2/PD1)

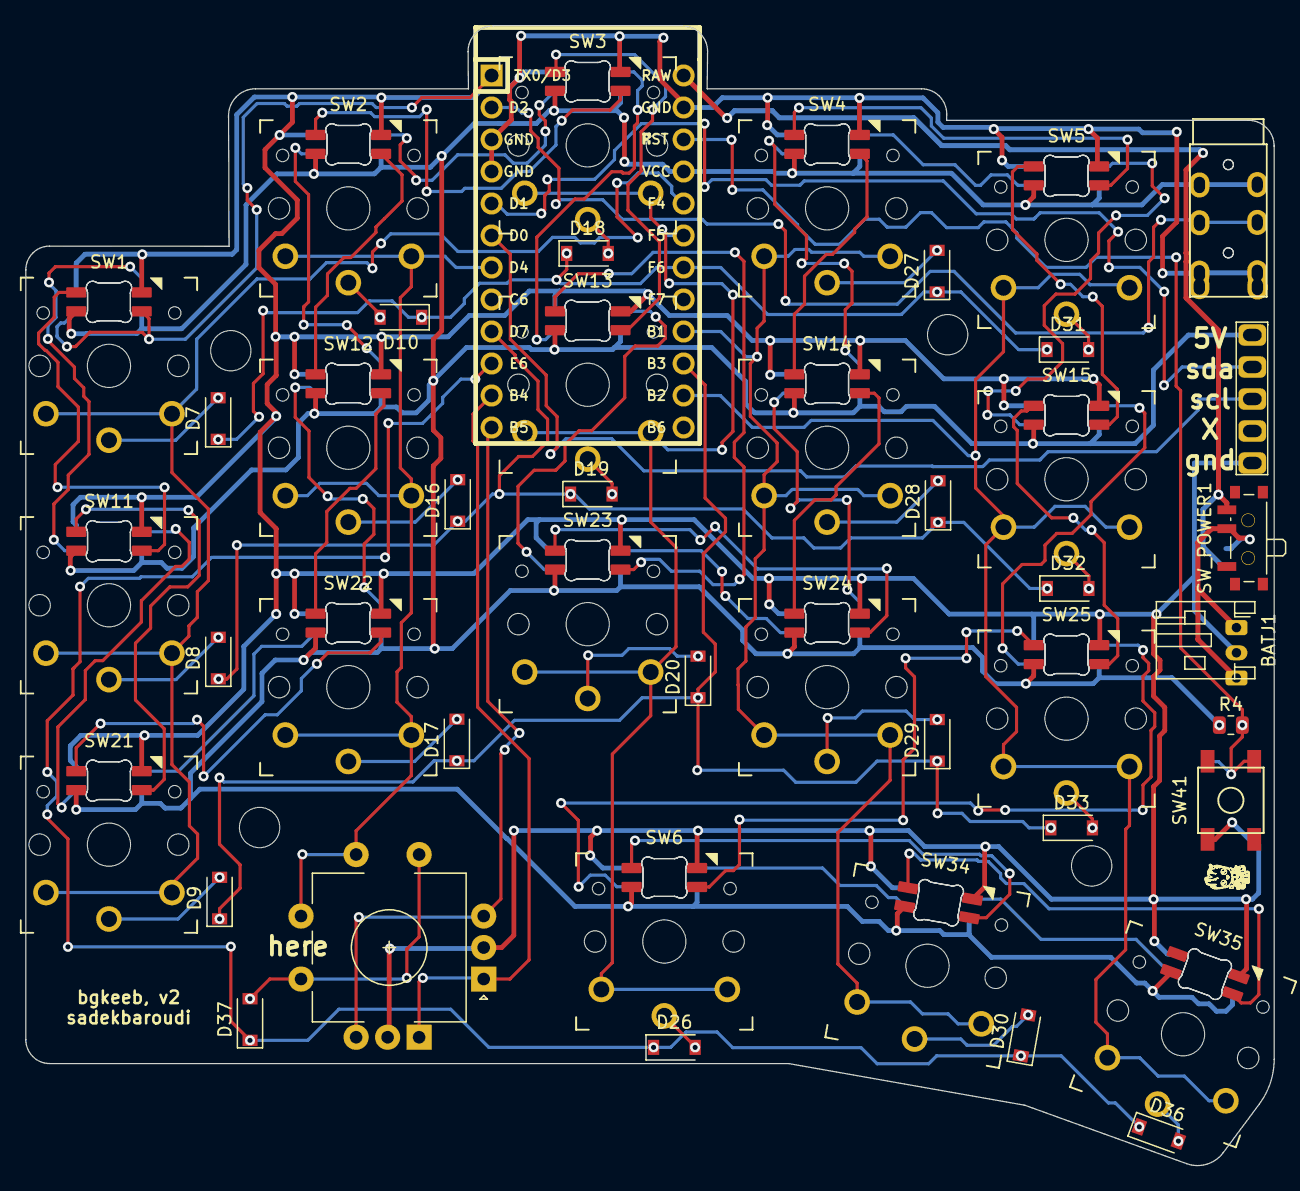
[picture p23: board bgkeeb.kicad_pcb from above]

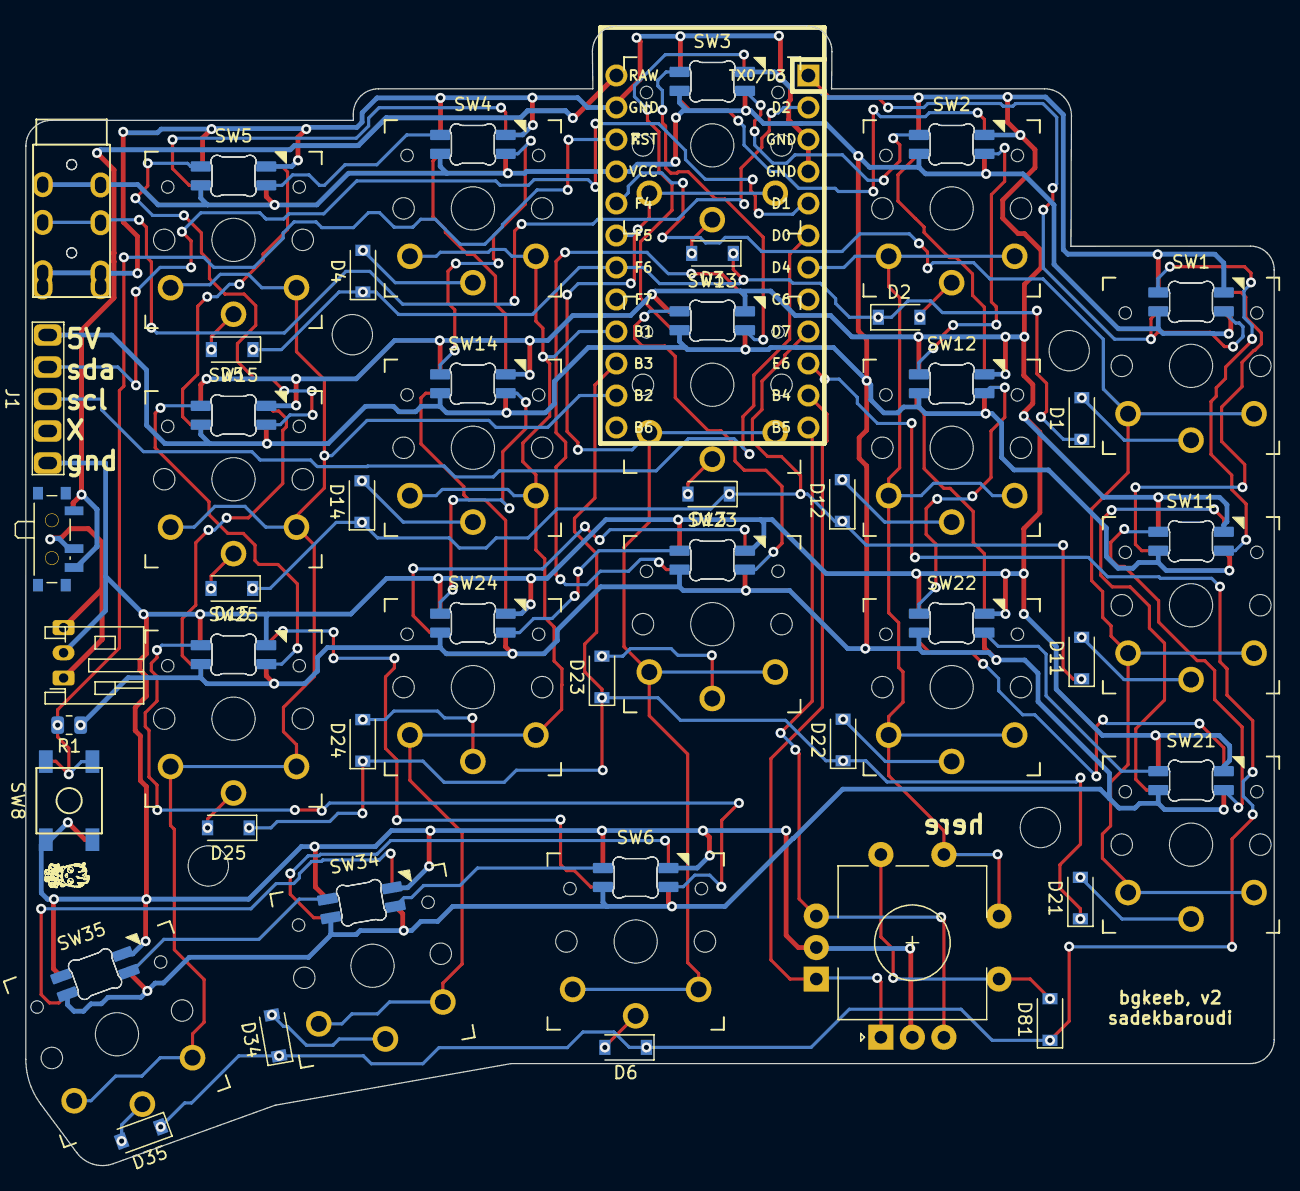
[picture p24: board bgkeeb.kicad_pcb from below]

Board: 2 copper layers, 99.1 x 90.5 mm, 104 parts (42 on the bottom side), 73 nets.

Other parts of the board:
BATJ1: Conn_01x02_Female; JST_PH_S2B-PH-K_1x02_P2.00mm_Horizontal_reversible

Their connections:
BT+: BATJ1.1; also elsewhere on the board
GND: BATJ1.2; also elsewhere on the board

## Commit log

2021-11-02 updated TRRS order
    [bgkeeb-B_Cu.gbr, bgkeeb-B_Mask.gbr, bgkeeb-B_Paste.gbr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]
2021-11-02 removed old gerber files, fixed rotary encoder on the back
    [babykeeb-B_Cu.gbr, babykeeb-B_Mask.gbr, babykeeb-B_Paste.gbr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]
2021-11-02 Updated to add mounting holes
    [bgkeeb-B_Cu.gbr, bgkeeb-B_Mask.gbr, bgkeeb-B_Paste.gbr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]
2021-11-04 case files for plate case
    [case-template.dxf, left-bottomplate.3mf, left-bottomplate.stl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]
2021-11-04 added full body case
    [left-bottomplate.3mf, left-bottomplate.stl, left-switchbody.3mf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]
2021-11-04 aux jack wasn't wired, no functional impact, just got DRC errors
    [bgkeeb-B_Cu.gbr, bgkeeb-B_Mask.gbr, bgkeeb-B_Paste.gbr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]
2021-11-05 wrong switch hole size
    [left-bottomplate.3mf, left-bottomplate.stl, left-switchbody.3mf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]
2021-11-08 the case was 1mm too small for the pcb, fixed
    [left-switchbody.3mf, left-switchbody.stl]
2021-11-09 fixed a lot of things
    [bgkeeb-B_Cu.gbr, bgkeeb-B_Mask.gbr, bgkeeb-B_Paste.gbr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]
2021-11-19 added EC11 covers
    [EC11-encoder-cap-M2-screw-holes.3mf, EC11-encoder-cap-small.3mf, EC11-encoder-cap.3mf]
2021-11-25 added image of pcbs
2021-11-25 added some text to describe the board
2021-11-26 updated BOM to include a couple of missing items, and readme to include firmware
2021-11-30 build guide had the wrong number of pro micros and resistors required
2021-12-02 v2 fixes the diode direction being flipped on the reverse side of the board
    [bgkeeb-B_Cu.gbr, bgkeeb-B_Mask.gbr, bgkeeb-B_Paste.gbr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]
2021-12-02 fixed confusion with diode direction, as it turns out, it's not an issue
2021-12-03 added plate gerbers for those that don't want to 3d print a case
    [bgkeeb-B_Cu.gbr, bgkeeb-B_Mask.gbr, bgkeeb-B_Paste.gbr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]
2021-12-03 added images and a readme for the plates
2021-12-03 missed a switch hole line in my last commit
    [bgkeeb-B_Cu.gbr, bgkeeb-B_Mask.gbr, bgkeeb-B_Paste.gbr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]
2021-12-09 added notes around the encoder placement
2021-12-14 missing mounting holes in bottom plate
    [left-bottomplate.3mf, left-bottomplate.stl]
2022-01-13 updated firmware link to fingerpunch
2022-02-11 Issue 2: Clarify how to handle the large legs on rotary encoders
2022-11-23 bgkeeb choc, work in progress
    [bgkeeb-B_Cu.gbr, bgkeeb-B_Mask.gbr, bgkeeb-B_Paste.gbr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]
2022-11-23 choc bgkeeb is complete
    [bgkeeb-B_Cu.gbr, bgkeeb-B_Mask.gbr, bgkeeb-B_Paste.gbr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]
2022-11-23 added choc case, renamed original case to mx case
    [left-switchbody-choc.stl, left-switchbody-mx.stl]
2023-11-08 added wireless pcb
    [bgkeeb-B_Cu.gbr, bgkeeb-B_Fab.gbr, bgkeeb-B_Mask.gbr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]
